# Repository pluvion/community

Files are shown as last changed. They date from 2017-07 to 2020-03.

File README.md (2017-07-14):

# Pluvi.On – Hackeando a chuva (Hacking the rain)
Image of Pluvion
 
Hoje no Brasil, existem aproximadamente 30 milhões de brasileiros expostos ao risco de enchentes e inundações. Além disso, existe uma projeção de impacto financeiro, onde as potenciais perdas anuais podem chegar a 4 bilhões de dólares até 2030 (Fonte: Swiss Re)

_Today in Brazil, there are approximately 30 million Brazilians exposed to the risk of flash floods and river floods. Moreover, there is financial impact: potential annual losses can reach 4 billion dollars by 2030 (Source: Swiss Re)_

Olhando este cenário alarmante iniciamos o desenvolvimento do Pluvi.On em jun/2016. Hoje somos um serviço de medição de chuva em tempo real e hiperlocalmente que envia informações de volume e intensidade da precipitação para quem precisar, população, entes governamentais e empresas.

_Looking at this alarming scenario we started the development of Pluvi.On in jun / 2016. Today we are a real-time and hyperlocal rainfall service that sends accumulated volume and precipitation rate data to anyone who needs it, population, government entities and companies._

Nosso sonho grande consiste em desenvolver novas estratégias de alerta de riscos (inundações, deslizamentos e chuvas intensas) para toda a população. Se possível, de maneira barata e escalável para que esta informação chegue a quem realmente precisa.

_Our big dream is to develop new risk alert strategies (floods, landslides and heavy rains) for the entire population. If possible, cheaply and scalable enough that this information gets to who really needs it._

Uma parte importante de tudo isso é o Pluvi.On, uma estação meteorológica Open Source e de baixo custo para ser espalhada na maior quantidade de pontos da cidade que pudermos!!! Chega de blá blá blá e vamos ao que interessa:

_An important part of all this is Pluvi.On itself, an inexpensive Open Source weather station to be spread out in as many points of the city as we can !!! That&#39;s enough talk let&#39;s see what matters:_

Você pode checar neste link todas as instruções para construção do seu próprio Pluvi!

_You can check in this link all the instructions for building your own Pluvi!_

https://www.instructables.com/member/PluviOn/

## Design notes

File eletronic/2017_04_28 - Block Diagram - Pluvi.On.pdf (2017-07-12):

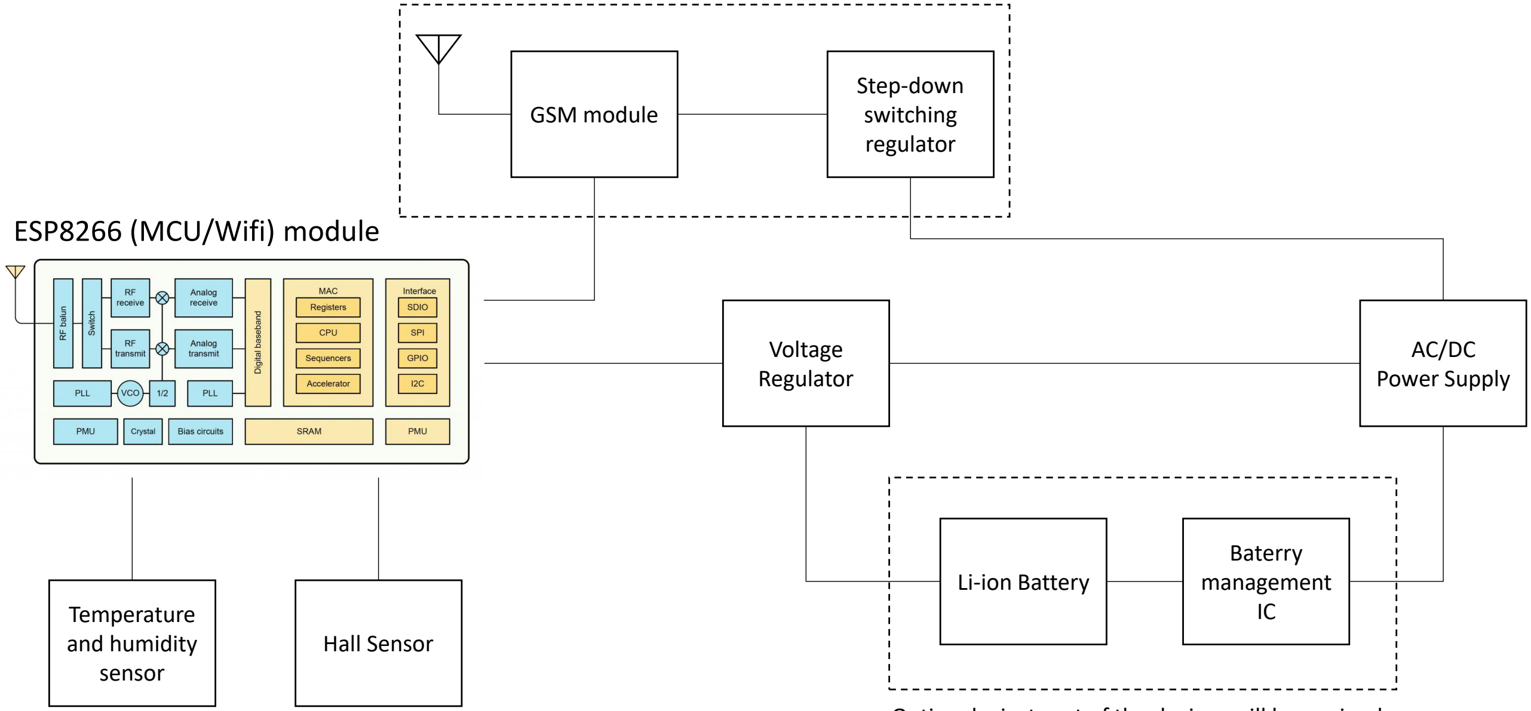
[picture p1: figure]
ESP8266 (MCU/Wifi) module; Hall Sensor; Temperature and humidity sensor; AC/DC Power Supply; Voltage Regulator; Li-ion Battery; GSM module; Baterry management IC; Step-down switching regulator

Optional – just part of the devices will be equiped with redundant power source

Optional – installed only when wifi is not available

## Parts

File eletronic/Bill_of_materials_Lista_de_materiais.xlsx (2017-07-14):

Descrição Portugues | English Description | Link | Qtd por unidade
Kit Colagem Acrilico / Cola S-320 / B25 | Acrylic Welding Kit S-320 / B25 |  | 20 ml
Sensor de Temperatura e Umidade DHT22 | Temperature and Humidity Sensor DHT22 | https://www.sparkfun.com/datasheets/Sensors/Temperature/DHT22.pdf | 1
Placa acrilico (480 mm x 300 mm x 2,4 mm) | Acrylic sheet (480 mm x 300 mm x 2.4 mm) | http://www.macedoplasticos.com.br/acrilicos.html | 1
Imã de neodimio N35 (4x2mm) | Neodymium magnet N35 (4x2mm) | http://www.imashop.com.br/ima-neodimio-n35-disco-4x2-mm-d0402p/p | 1
Sensor Hall (DRV5023 SMD) | Hall Sensor (DRV5023 SMD) | http://www.ti.com/product/DRV5023 | 1
Resistor 0805 10K SMD | Resistor 0805 10K SMD | http://www.mouser.com/ProductDetail/Kamaya/RMC1-10K1200FTP/ | 2
Capacitor Ceramico 0805 10uF SMD | Ceramic Capacitor 0805 10uF SMD | http://www.mouser.com/ProductDetail/Vishay-Vitramon/VJ0805G106KXQTW1BC/ | 1
Conector 1014 femea 14 pinos para barra de pinos | Flip pin 14 pins | https://www.sparkfun.com/products/14086 | 2
Barra de Pinos 90 graus | Break Away Male Headers - Right Angle | https://www.sparkfun.com/products/553 | 2 pinos
Barra de Pinos reto | Break Away Headers - Straigh | https://www.sparkfun.com/products/116 | 2 pinos
Conector femea c/ shell | 2-pin Wire to board connector 2.54 | https://www.alibaba.com/product-detail/17-pin-electronic-wire-to-board_60602562246.html | 2
Nodemcu LoLin v3 | Nodemcu LoLin v3 | https://github.com/nodemcu/nodemcu-devkit | 1
Fonte DC 5V 500mA ou maior | DC 5V 500mA Power Supply | https://www.sparkfun.com/products/12889 | 1
Tipping Bucket - Fabricado conforme projeto | Tipping Bucket - Manufactured according to design | https://github.com/pluvion/community/blob/master/design/3D_Parts/Bucket_onepiece.stl | 1
Stevenson Screen - Fabricado conforme projeto | Stevenson Screen - Manufactured according to design | https://github.com/pluvion/community/blob/master/design/3D_Parts/Stevenson_screen.stl | 1
PCB - Fabricado conforme projeto | PCB - Manufactured according to design | https://github.com/pluvion/community/tree/master/eletronic | 1
Passa Fio de borracha 3 mm | Grommet 3 mm | https://www.alibaba.com/product-detail/Custom-made-waterproof-molded-OEM-rubber_60619949840.html | 2
Eixo de latão usinado ou pino de 40 x 2,65 mm | Machined brass shaft or simple stainless pin 40 x 2.65 mm | https://www.alibaba.com/product-detail/High-quality-precision-M2-Stainless-steel_60147705078.html | 1
Fita Hellerman | Assorted Cable ties | https://www.hellermanntyton.com/products/cable-ties-inside-serrated/t80r/111-08010 | 2
Pincel | Brush |  | Tools
Ferro de solda / Estacao de solda | Soldering Iron / Soldering Station |  | Tools
Cola quente | Hot Glue |  | Tools

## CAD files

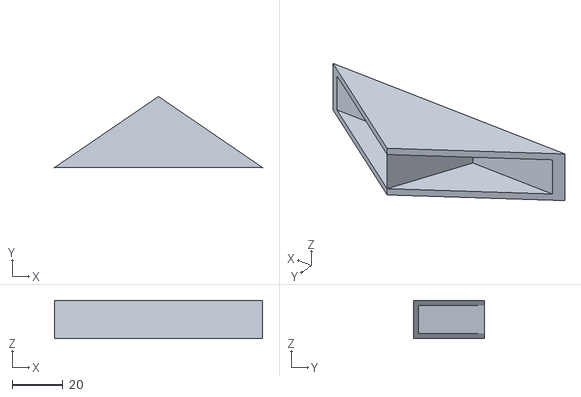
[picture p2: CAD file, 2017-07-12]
design/3D_Parts/Bucket_main.stl
82.0 x 28.0 x 15.0

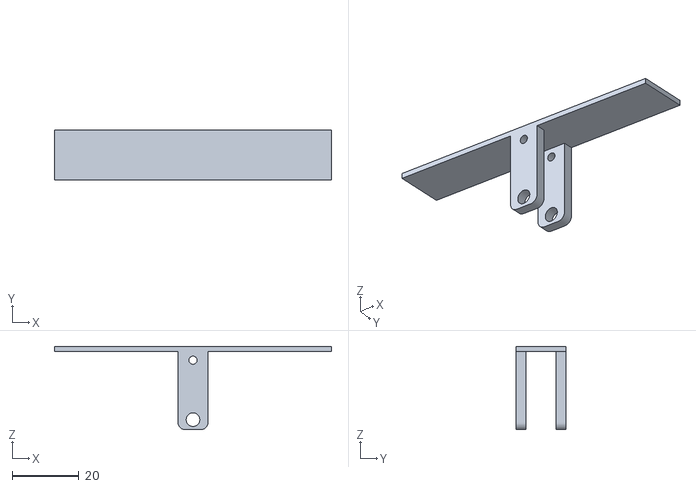
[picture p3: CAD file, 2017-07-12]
design/3D_Parts/Bucket_Base.stl
83.0 x 15.0 x 25.0

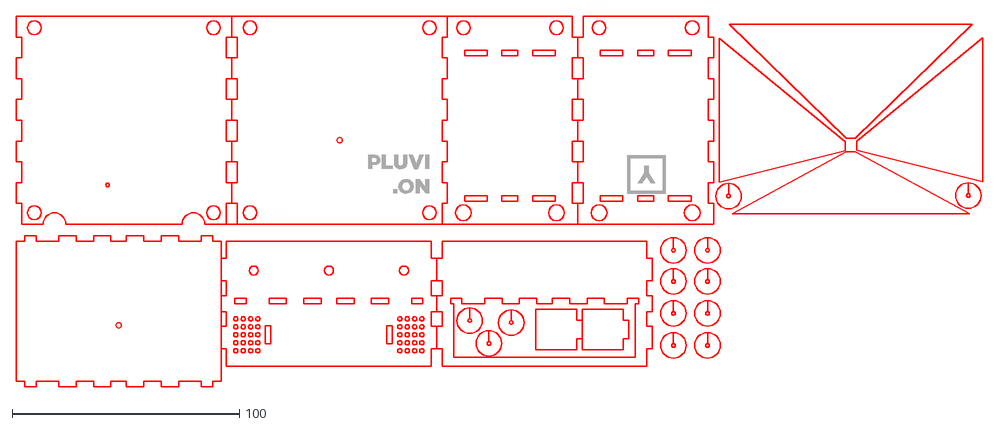
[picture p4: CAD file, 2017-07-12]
design/Lasercut_Parts/Pluvion_community_2D.dxf
425.8 x 163.1

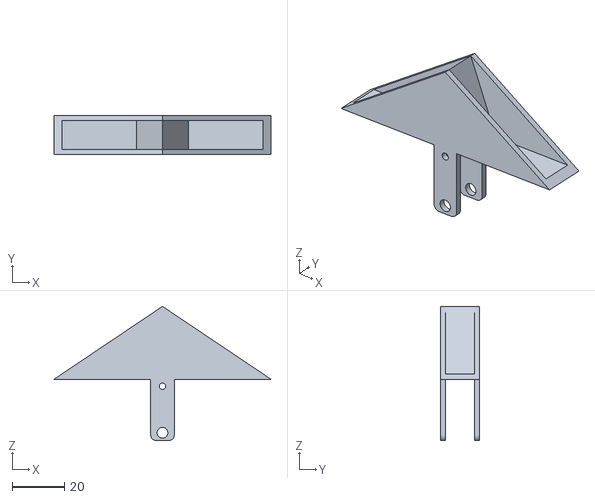
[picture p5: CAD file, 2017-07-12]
design/3D_Parts/Bucket_onepiece.stl
83.0 x 15.0 x 51.4

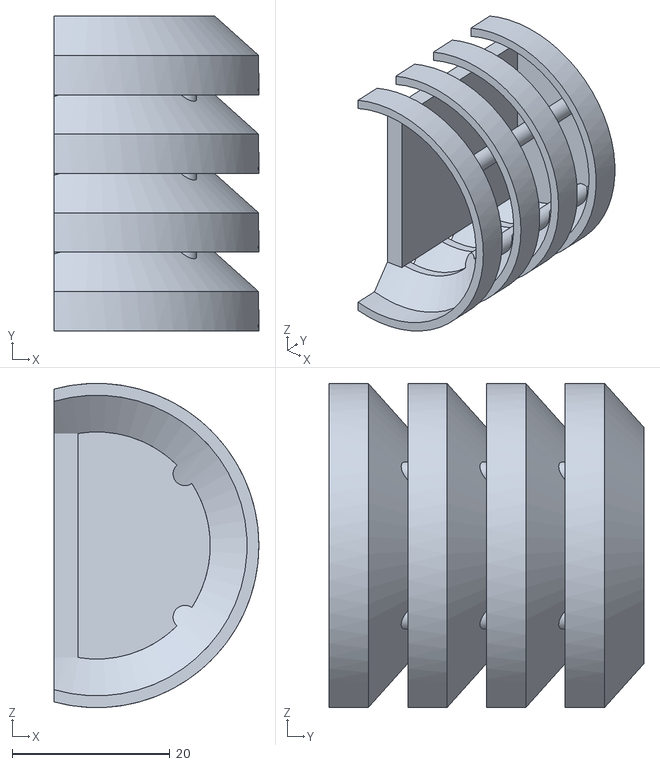
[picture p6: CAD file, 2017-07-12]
design/3D_Parts/Stevenson_screen.stl
26.0 x 40.0 x 41.2

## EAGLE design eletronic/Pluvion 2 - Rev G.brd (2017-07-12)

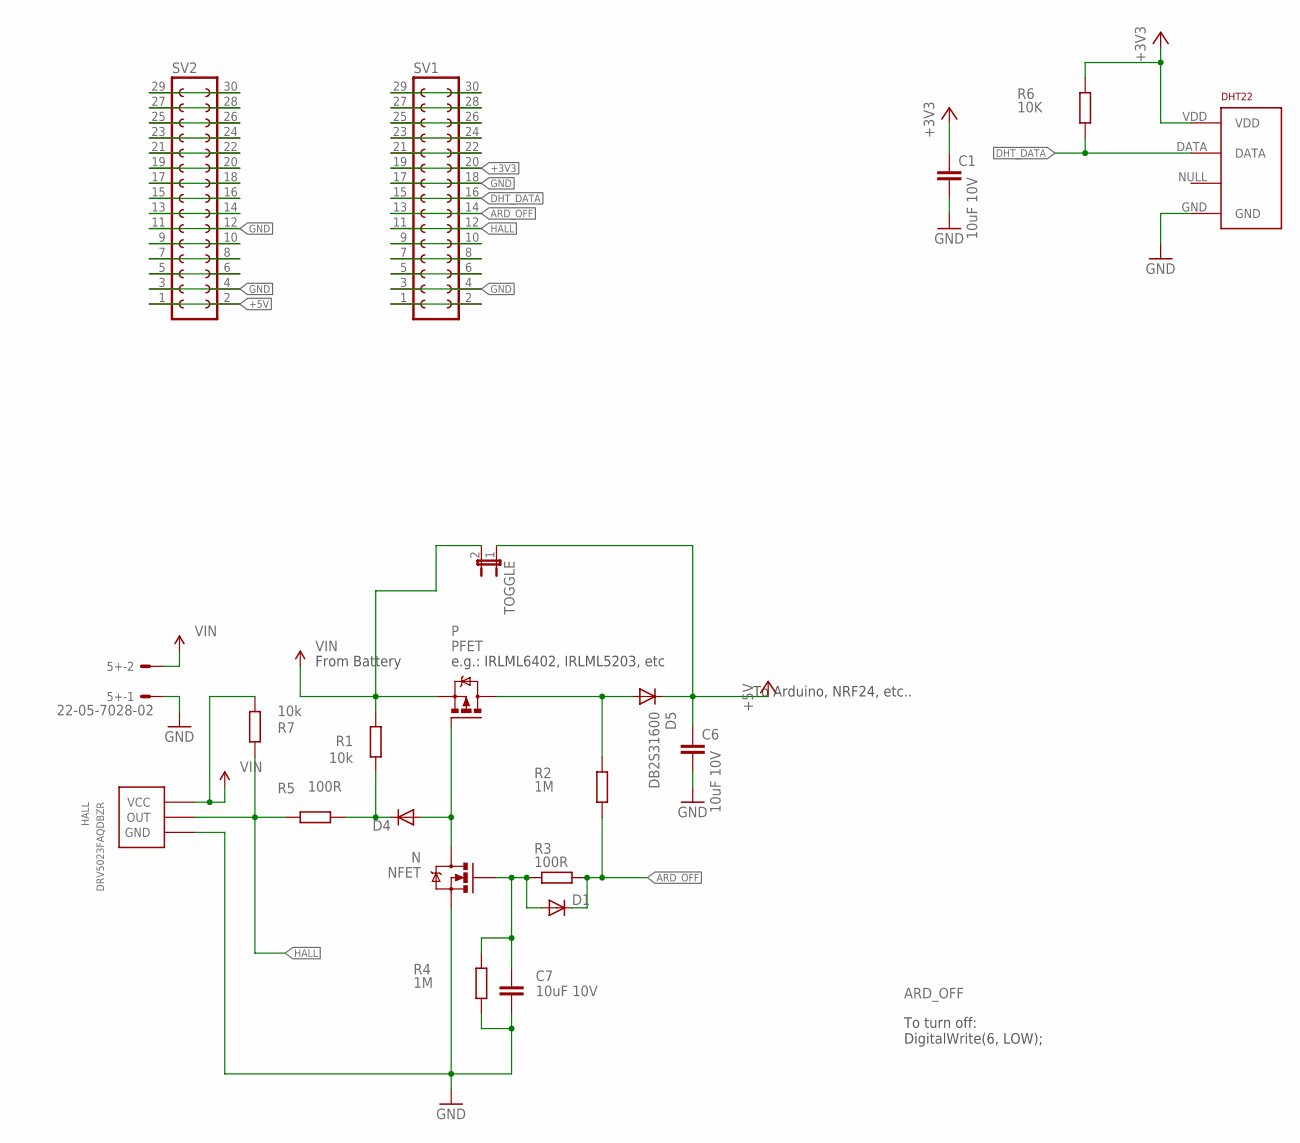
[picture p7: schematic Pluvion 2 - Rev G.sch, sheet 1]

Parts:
5+: 22-05-7028-02; 7395-02
C1, C6, C7: 10uF 10V; C0805
D1, D4: DIODESOD; SOD-323
D5: DB2S31600; SMA-DIODE
DHT22: RHT03_DHT-22_AM2302RA; RHT03_DHT-22/RA
HALL: DRV5023FAQDBZR; SOT23
N: NFET; SOT23
P: PFET; MICRO3
R1, R7: 10k; R0805
R2, R4: 1M; R0805
R3, R5: 100R; R0805
R6: 10K; R0805
SV1, SV2: FE15-2
TOGGLE: JUMPER-2PTH; 1X02

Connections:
+3V3: C1.1, DHT22.VDD, R6.2, SV1.19, SV1.20
+5V: C6.1, D5.C, SV2.1, SV2.2, TOGGLE.1
ARD_OFF: D1.1 (C), R2.1, R3.2, SV1.13, SV1.14
BUTTONS: D4.2 (A), N.3 (D), P.1 (G)
DHT_DATA: DHT22.DATA, R6.1, SV1.15, SV1.16
GND: 5+.1, C1.2, C6.2, C7.2, DHT22.GND, HALL.3 (GND), N.2 (S), R4.1, SV1.3, SV1.4, SV1.17, SV1.18, SV2.3, SV2.4, SV2.11, SV2.12
HALL: HALL.2 (OUT), R5.2, R7.2, SV1.11, SV1.12
unnamed: D5.A, P.3 (D), R2.2
unnamed: C7.1, D1.2 (A), N.1 (G), R3.1, R4.2
unnamed: SV1.1, SV1.2
unnamed: SV1.5, SV1.6
unnamed: SV1.7, SV1.8
unnamed: SV1.9, SV1.10
unnamed: D4.1 (C), R1.1, R5.1
unnamed: SV1.21, SV1.22
unnamed: SV1.23, SV1.24
unnamed: SV1.25, SV1.26
unnamed: SV1.27, SV1.28
unnamed: SV1.29, SV1.30
unnamed: SV2.5, SV2.6
unnamed: SV2.7, SV2.8
unnamed: SV2.9, SV2.10
unnamed: SV2.13, SV2.14
unnamed: SV2.15, SV2.16
unnamed: SV2.17, SV2.18
unnamed: SV2.19, SV2.20
unnamed: SV2.21, SV2.22
unnamed: SV2.23, SV2.24
unnamed: SV2.25, SV2.26
unnamed: SV2.27, SV2.28
unnamed: SV2.29, SV2.30
VIN: 5+.2, HALL.1 (VCC), P.2 (S), R1.2, R7.1, TOGGLE.2

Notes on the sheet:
e.g.: IRLML6402, IRLML5203, etc
To Arduino, NRF24, etc..
To turn off: DigitalWrite(6, LOW);
From Battery

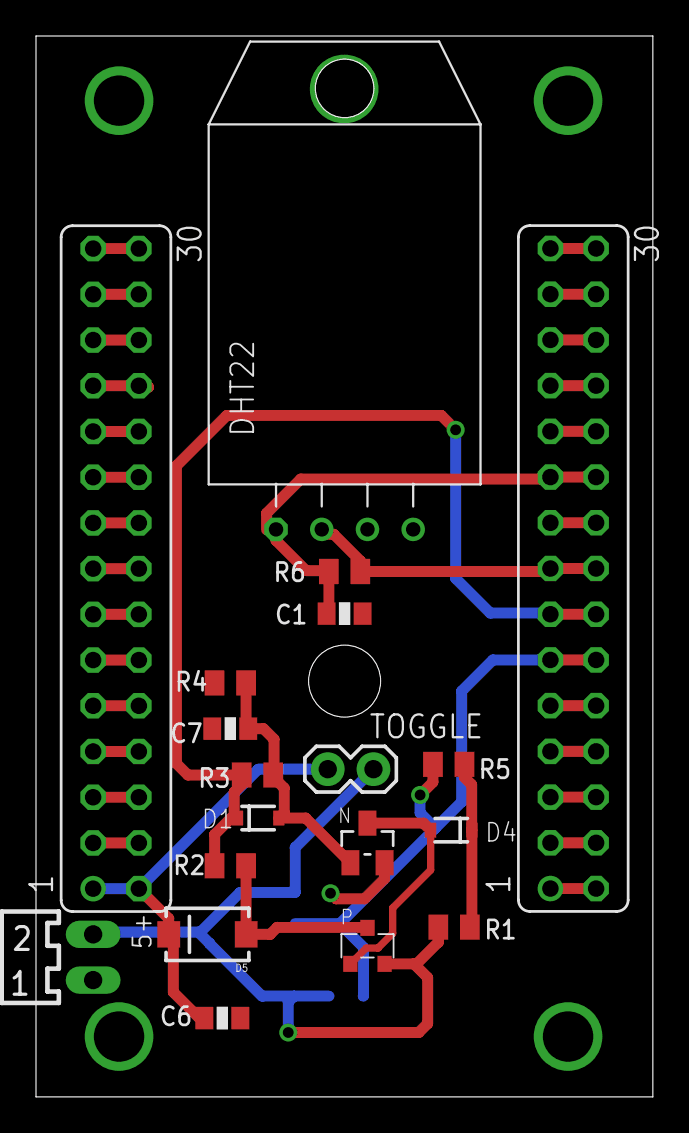
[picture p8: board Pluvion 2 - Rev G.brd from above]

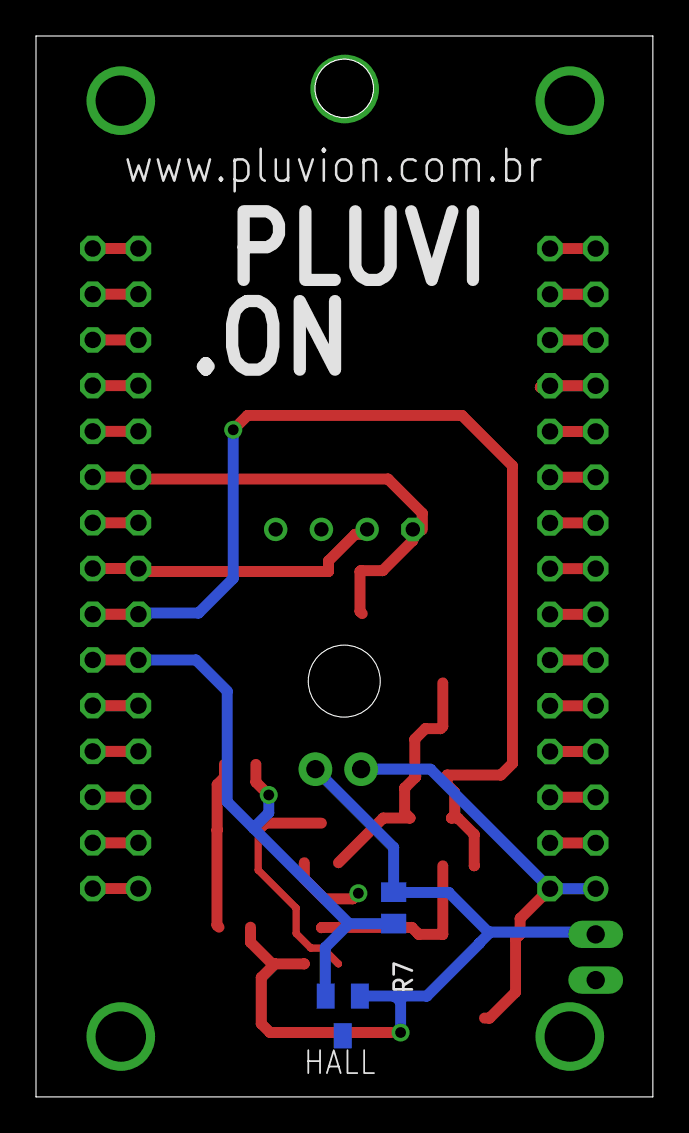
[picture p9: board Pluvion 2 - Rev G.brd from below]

Board: 2 copper layers, 34.3 x 58.9 mm, 21 parts (2 on the bottom side), 32 nets.

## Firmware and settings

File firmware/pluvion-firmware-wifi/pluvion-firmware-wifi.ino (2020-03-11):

/**
 * Pluvi.On WiFi Firmware
 * 
 *       FILE: pluvion_firwmware_wifi.ino
 *    VERSION: 2.0.0.W
 *    LICENSE: Creative Commons 4
 *    AUTHORS:
 *             Pedro Godoy <pedro@pluvion.com.br>
 *             Hugo Santos <hugo@pluvion.com.br>
 * 
 *       SITE: https://www.pluvion.com.br
 */
#include <FS.h>
#include <DHT.h>
#include <ESP8266WiFi.h>
#include <WiFiUdp.h>
#include <PluviOn.h>
PluviOn utils;

/////ATTENTION!!!! CHANGES SHOULD BE DONE IN COMPILATION TIME///
///BEGIN
// STATION CONFIG
const char *ssid           = "PG_hotspot";
const char *password       = "0102030405";
const String STATION_ID    = "31";
#define  SLEEP_PERIOD      900000 //15 minutes
#define SERVER_ADDR        "3.87.153.3"
#define SERVER_PORT      10000
///END
/////ATTENTION!!!! CHANGES SHOULD BE DONE IN COMPILATION TIME///

// WIFI
WiFiClient wf_client;

// SYSTEM SLEEP CONTROL
unsigned long sleepCounter = 0; // Sleep time counter


// SYSTEM DEFINES
#define SYSTEM_BAUDRATE 115200
const String DATA_DIR = "/data";
bool fs_is_active = false;

// PINS DEFINES
#define PIN_RESET_MONO D1 // pin reset mono
#define PIN_DHT D5        // pin where the dht22 is connected
#define PIN_SYSTEM_FORMAT D6 // pin full reset
#define PIN_HALL D7       // pin where Hall sensor is connected
#define PIN_RTC_SDA GPIO_ID_PIN(2)
#define PIN_RTC_SCL GPIO_ID_PIN(4)

// TEMPERATURE + HUMIDITY SENSOR
#define DHT_TYPE DHT22 //DHT type
DHT dht(PIN_DHT, DHT_TYPE, 20); // Initialize DHT sensor
#define DHT_SENSOR_READING_DELAY 600000
#define DHT_SENSOR_READING_FAILURE_DELAY 180000
#define DHT_SENSOR_READING_FAILURE_ATTEMPTS_LIMIT 2
unsigned long lastDHTReadingInMillis = 0;    // The last DHT reading time in ms
unsigned long currentDHTReadingInMillis = 0; // Current DHT reading in millis
boolean DHTSensorReadingFailure = false;
int DHTSensorFailedReadingAttempts = 0;
volatile float humidity = 0;          // Read air humidity in %
volatile float temperature = 0;       // Read temperature as Celsius
volatile float computedHeatIndex = 0; // Compute heat index in Celsius

// RAIN SENSOR
#define DELAY_HALL_SENSOR_DEBOUNCING 100 // Delay in ms to debounce hall sensor
volatile int tipCounter = 0;             // Store the bucket tip counter
volatile int realTipCount = 0;           // Checked tip counter
volatile int lastTipCount = 0;           // The last tip count total
unsigned long curBucketReadingInMs = 0;  // Current rain sensor reading in millis
unsigned long lastBucketReadingInMs = 0; // The last rain sensor reading time in ms
const float CONTRIBUTION_AREA = 7797.0; // Contribuition area in mm2
volatile float rainVolume = 0;          // The rain accumulated volume

void init_dht() {
  dht.begin();
}

void count_tip_bucket() {
  tipCounter++;
  Serial.print(F("[count_tip_bucket] - Tip counter: "));
  Serial.println(tipCounter);
  Serial.print(F("[count_tip_bucket] - Real tip count: "));
  Serial.println(realTipCount);
  Serial.print(F("[count_tip_bucket] - Last tip count: "));
  Serial.println(lastTipCount);
  detachInterrupt(PIN_HALL);
  read_hall_sensor();
  attach_interruption();
  }

void attach_interruption() {
  Serial.println(F("[attach_interruption] - Attaching"));
  attachInterrupt(PIN_HALL, count_tip_bucket, FALLING);
  Serial.println(F("[attach_interruption] - Done"));
}

void read_hall_sensor() {
  // Current millis mark
  curBucketReadingInMs = millis();

  // Check if the configured delay has passed
  if (
      ((curBucketReadingInMs - lastBucketReadingInMs) > DELAY_HALL_SENSOR_DEBOUNCING) || // delay
      (lastBucketReadingInMs == 0)                                                       // first time
  ) {
    // Any increment since the last time?
    if (tipCounter > lastTipCount) {

      // Increase the tip bucket count
      realTipCount++;
      Serial.print(F("REAL TIP COUNT: "));
      Serial.println(realTipCount);

      // Update last tip counter value
      lastTipCount = tipCounter;
    }

    // Store the current millis for the next iteration
    lastBucketReadingInMs = curBucketReadingInMs;
  }
}

void read_dht_sensor() {
  // Current millis mark
  currentDHTReadingInMillis = millis();

  if (
    DHTSensorReadingFailure &&                                                                    // Fail
    ((currentDHTReadingInMillis - lastDHTReadingInMillis) >= DHT_SENSOR_READING_FAILURE_DELAY) && // The time hasn' passed yet
    (DHTSensorFailedReadingAttempts <= DHT_SENSOR_READING_FAILURE_ATTEMPTS_LIMIT)                 // Number of attempts
  ) {
    Serial.println(F("[read_dht_sensor] - DHT reading failure"));
    Serial.print(F("[read_dht_sensor] - DHT reading retries: "));
    Serial.println(DHTSensorFailedReadingAttempts);

    DHTSensorFailedReadingAttempts++;

    Serial.println(F("[read_dht_sensor] - Reading DHT..."));
    get_dht_data();
  }

  // Check if the configured delay has passed
  if ((currentDHTReadingInMillis - lastDHTReadingInMillis) >= DHT_SENSOR_READING_DELAY || // delay
    (lastDHTReadingInMillis == 0)                                                         // first time
  ) {
    Serial.println(F("[read_dht_sensor] - Reading DHT..."));
    get_dht_data();
  }
}

void get_dht_data() {

  // Reading temperature or humidity takes about 250 milliseconds!
  // Sensor readings may also be up to 2 seconds 'old' (its a very slow sensor)
  humidity = dht.readHumidity();

  // Read temperature as Celsius
  temperature = dht.readTemperature();

  // Check if any reads failed and exit early (to try again).
  if (isnan(humidity) || isnan(temperature)) {
    Serial.println(F("[get_dht_data] - ERROR - Failed to read from DHT sensor!"));

    // Indicates a failure in readings
    DHTSensorReadingFailure = true;

    // Fix humidity, temperature and computed heat index
    humidity = isnan(humidity) ? -999 : humidity;
    temperature = isnan(temperature) ? -999 : temperature;
    computedHeatIndex = -999;

    // Store the current millis for the next iteration
    lastDHTReadingInMillis = currentDHTReadingInMillis;

    return;
  }

  // Reset failure flags
  DHTSensorFailedReadingAttempts = 0;
  DHTSensorReadingFailure = false;

  // Compute heat index in Celsius (isFahreheit = false)
  computedHeatIndex = dht.computeHeatIndex(temperature, humidity, false);
  computedHeatIndex = (computedHeatIndex > 100) ? 0 : computedHeatIndex;

  Serial.print(F("[get_dht_data] - temperature (C)      : "));
  Serial.println(temperature);

  Serial.print(F("[get_dht_data] - humidity (%)         : "));
  Serial.println(humidity);

  Serial.print(F("[get_dht_data] - computedHeatIndex (C): "));
  Serial.println(computedHeatIndex);

  // Store the current millis for the next iteration
  lastDHTReadingInMillis = currentDHTReadingInMillis;
}

void print_fs_info() {
  FSInfo fs_info;
  SPIFFS.info(fs_info);

  float used_space = (float) fs_info.usedBytes/fs_info.totalBytes;
  float free_space = (float) (1 - used_space);

  Serial.print(F("[print_fs_info] - Filesystem Total: "));
  Serial.println(fs_info.totalBytes);

  Serial.print(F("[print_fs_info] - Filesystem Used: "));
  Serial.println(fs_info.usedBytes);

  Serial.print(F("[print_fs_info] - Filesystem Used %: "));
  Serial.println(used_space);

  Serial.print(F("[print_fs_info] - Filesystem Free %: "));
  Serial.println(free_space);
}

void read_sensors() {
  Serial.println(F("[read_sensors] - Begin"));

  // Reads the hall sensor
  read_hall_sensor();

  // Reads the DHT Sensor Info
  read_dht_sensor();

  Serial.println(F("[read_sensors] - Done"));
}

void save_message(String message){
  Serial.print(F("[save_message] - Saving Message: \""));
  Serial.print(message);
  Serial.println(F("\""));

  Serial.print(F("[save_message] - Free Space: "));
}
  
int wifi_quality() {
  long rssi = WiFi.RSSI();

  int percent = 0;
  if(rssi > -50) {
    percent = 100;
  } else if(rssi > -55) {
    percent = 90;
  } else if(rssi > -62) {
    percent = 80;
  } else if(rssi > -65) {
    percent = 70;
  } else if(rssi > -68) {
    percent = 60;
  } else if(rssi > -74) {
    percent = 50;
  } else if(rssi > -79) {
    percent = 40;
  } else if(rssi > -83) {
    percent = 30;
  } else if(rssi > -88) {
    percent = 20;
  } else if(rssi > -93) {
    percent = 10;
  }

  Serial.print("[wifi_quality] - rssi/percent: ");
  Serial.print(rssi);
  Serial.print(F("/"));
  Serial.println(percent);

  return percent;
}

float fs_free_space() {
  FSInfo fs_info;
  SPIFFS.info(fs_info);

  float used_space = (float) fs_info.usedBytes/fs_info.totalBytes;
  float free_space = (float) (1 - used_space);

  Serial.print("[fs_free_space] - Used: ");
  Serial.println(used_space);

  Serial.print("[fs_free_space] - Free: ");
  Serial.println(free_space);

  return free_space;
}

String build_message() {
  String message = "i;";

  message += STATION_ID;
  message += ";";

  message += realTipCount;
  message += ";";

  message += "0;"; // Raining

  message += temperature;
  message += ";";

  message += humidity;
  message += ";";

  message += wifi_quality();
  message += ";";

  message += "0"; // crc

  Serial.print(F("[build_message] - Message (i;id;timestamp;bt;raining;tp;rh;sigs;crc): "));
  Serial.println(message);

  return message;
}

void delete_messages(String send_result){

  if(send_result == "ok") {
    Serial.println(F("[delete_messages] - Deleting files:"));
    utils.FSPrintFileList();
  
    utils.FSDeleteFiles(DATA_DIR);
    Serial.println(F("[delete_messages] - Done."));
  
    Serial.println(F("[delete_messages] - File list:"));
    utils.FSPrintFileList();
  } else {
    Serial.print(F("[delete_messages] - Can't delete, socket response: '"));
    Serial.print(send_result);
    Serial.println(F("'"));
  }
}

String read_messages() {
  Serial.println(F("[read_messages]"));
}

String send_messages() {
  if(fs_is_active){
    // Open directory
    Dir dir = SPIFFS.openDir(DATA_DIR);
    Serial.print(F("[send_messages] - Files in \""));
    Serial.print(DATA_DIR);
    Serial.println(F("\" directory:"));
    Serial.println(F("[send_messages] - ---------"));
    File f;
    String messages;
    while (dir.next()) {
      Serial.print(F("[send_messages] - "));
      Serial.println(dir.fileName());
      // Open file
      f = SPIFFS.open(dir.fileName(), "r");

      if (!f) {
        Serial.print(F("[send_messages] - Unable To Open '"));
        Serial.print(dir.fileName());
        Serial.println(F("' for Reading"));
      } else {

        // Group messages
        while (f.position() < f.size()) {
          messages += f.readStringUntil('\n');
          messages += '\n';
        }

        f.close();
      }
    }

    Serial.println(F("[send_messages] - Message payload:"));
    Serial.print(messages);
    
    // Send all messages
    return send_message(messages);

  } else {
      Serial.println(F("[send_messages] - Filesystem is not mounted"));
      return "not_mounted";
  }
}

String send_message(String message){
  String result = "";

  Serial.print(F("[send_message] - Connecting to "));
  Serial.print(SERVER_ADDR);
  Serial.print(":");
  Serial.println(SERVER_PORT);

  boolean wf_connected = wifi_connected();

  if(wf_connected > 0) {
    Serial.println(F("[send_message] - Connected!"));
    Serial.println(F("[send_message] - Transmitting message: "));
    Serial.print(message);
  
    // Post Data
    wf_client.print(message);

    Serial.println(F("[send_message] - Handling response"));

    // Handle result
    while (wf_client.connected()) {
      if (wf_client.available()) {
        result = wf_client.readStringUntil('\r');
        Serial.print(F("[send_message] - Return: "));
        Serial.println(result);
        break;
      }
    }

    Serial.println(F("[send_message] - Closing connection"));

    // Close connection
    wf_client.stop();
    
  } else {
    Serial.println(F("[send_message] - FAIL - Can't connect, can't transmit, aborted."));
  }

  Serial.println(F("[send_message] - Done"));
  return result;
}

void init_fs(){
  Serial.println(F("[init_fs] - Begin"));

  if (SPIFFS.begin()) {
    fs_is_active = true;
    Serial.println(F("[init_fs] - SPIFFS is active"));
  } else {
    Serial.println(F("[init_fs] - FATAL! Unable to activate SPIFFS"));
    while(1);
  }

  Serial.println(F("[init_fs] - Done"));
}

void wifi_init() {
  wifi_setup();
  wifi_connected();
}

void wifi_setup() {
  Serial.print(F("[wifi_setup] - Connecting to SSID: "));
  Serial.println(ssid);
  WiFi.begin(ssid, password);
  while (WiFi.status() != WL_CONNECTED) {
    delay(500);
    Serial.print(".");
  }
}

boolean wifi_connected() {
  Serial.print(F("[wifi_connected] - Connecting to SSID: "));
  Serial.println(ssid);

  int conn_counter = 20;
  while (!wf_client.connect(SERVER_ADDR, SERVER_PORT)) {
    Serial.print(F("[wifi_connected] - Connection Failed ("));
    Serial.print(conn_counter);
    Serial.println(F(")"));

    delay(1000);
    
    conn_counter--;

    if(conn_counter < 0) break;
  }
  
  if(conn_counter > 0) {
    Serial.println(F("[wifi_connected] - WiFi Connected"));
    return true;
  } else {
    Serial.println(F("[wifi_connected] - WiFi NOT Connected"));
    return false;
  }
}

 
/**
 * Put the system to sleep
 */
void system_sleep() {
//  wifi_set_sleep_type(LIGHT_SLEEP_T);
  Serial.println(F("[system_sleep] - Modem is sleeping"));

  delay(SLEEP_PERIOD);
//  unsigned long sleepCounter = millis();
//  while ((millis() - sleepCounter) < SLEEP_PERIOD);

  Serial.println(F("[system_sleep] - Modem up and running"));
}

void init_ntp() {
  Serial.println(F("[init_ntp] - Starting"));
  
  Serial.println(F("[init_ntp] - Updating"));
  
  Serial.println(F("[init_ntp] - Done"));
}

void format_fs() {
  Serial.println(F("[format_fs] - Formatting File System, please wait..."));
  utils.FSFormat();
  Serial.println(F("[format_fs] - Done."));
}

void config_pins() {
  Serial.println(F("[config_pins] - Begin"));

  // RAIN
  pinMode(PIN_HALL, INPUT_PULLUP);

  // RESET
  pinMode(PIN_RESET_MONO, OUTPUT);
  digitalWrite(PIN_RESET_MONO, HIGH);
  pinMode(PIN_SYSTEM_FORMAT, INPUT_PULLUP);
  if (digitalRead(PIN_SYSTEM_FORMAT) == 0) {
    Serial.println(F("[config_pins] - Format FS pin active. Formatting..."));
    format_fs();
  }

  Serial.println(F("[config_pins] - Done"));
}

void reset_bucket_tip_counter() {
  Serial.print(F("[reset_bucket_tip_counter] - Tip counter: "));
  Serial.println(tipCounter);

  Serial.print(F("[reset_bucket_tip_counter] - Real tip count: "));
  Serial.println(realTipCount);

  Serial.print(F("[reset_bucket_tip_counter] - Last tip count: "));
  Serial.println(lastTipCount);

  lastTipCount = 0;
  realTipCount = 0;
  tipCounter = 0;
  rainVolume = 0;
}

void setup() {
  Serial.begin(SYSTEM_BAUDRATE);

  Serial.println(F("\n\n[setup] - Init =========================="));
  
  config_pins();

  wifi_init();

  init_fs();

//  format_fs();

  init_dht();
    
  attach_interruption();
}

void loop() {
  Serial.println(F("\n\n[loop] - Begin =========================="));
  read_sensors();
  String message = build_message();
  reset_bucket_tip_counter();
//  save_message(message);
  String send_result = send_messages();
//  delete_messages(send_result);
  attach_interruption();
  system_sleep();
}

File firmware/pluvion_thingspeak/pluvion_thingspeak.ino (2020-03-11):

/**
 * Pluvi.On WiFi Community Firmware
 * 
 *       FILE: pluvion_community_firwmware.ino
 *    VERSION: 0.0.3.C
 *    LICENSE: Creative Commons 4
 *    AUTHORS:
 *             Pedro Godoy <pedro@pluvion.com.br>
 *             Hugo Santos <hugo@pluvion.com.br>
 * 
 *       SITE: https://github.com/pluvion/firmware
 *             https://www.pluvion.com.br
 */

// Insert your key here
const String apiKey = "VJXMP2062EHMRFT6"; // THINGSPEAK CHANNEL API KEY https://www.mathworks.com/help/thingspeak/channel-control.html

/********************
 * 
 * YOU DON'T NEED TO CHANGE ANYTHING BELOW THIS POINT
 * 
 *********************/

// Libraries
#include <FS.h> // FS must be the first
#include <DHT.h>
#include <ESP8266WiFi.h>
#include <WiFiManager.h>

// System Config (must come before #include <PluviOn.h>)
#define PLV_DEBUG_ENABLED true
#define PLV_SYSTEM_BAUDRATE 115200

#include <PluviOn.h>
PluviOn pluvion;

// Debug voltage in (enable ESP.getVcc())
ADC_MODE(ADC_VCC);

// PINS
#define PIN_DHT D5       // pin where the dht22 is connected
#define PIN_POWER_OFF D6 // pin where toggle is connected
#define PIN_HALL D7      // pin where Hall sensor is connected
#define PIN_ERASE D0

// |------------------------------------------|
// |     DHT Sensor Reading Interval in ms    |
// |------------------------------------------|
// |   INTERVAL  |   FREQ.  |  # MSGS/DAY     |
// |-------------|----------|-----------------|
// |  1.800.000  |  30 min  |     48 msg/day  |
// |  1.200.000  |  20 min  |     72 msg/day  |
// |    900.000  |  15 min  |     96 msg/day  |
// |    600.000  |  10 min  |    144 msg/day  |
// |    300.000  |   5 min  |    288 msg/day  |
// |     60.000  |   1 min  |  1.440 msg/day  |
// |     30.000  |  30 sec  |  2.880 msg/day  |
// |-------------|----------|-----------------|
//
// ATTENTION!
// You must consider the available storage size and the message size
// More messages, less space in case of lost connection

#define DHT_SENSOR_READING_DELAY 600000
#define DHT_SENSOR_READING_FAILURE_DELAY 180000
#define SEND_OFFLINE_MESSAGES_DELAY 120000

// READING PERIODS AND DEBOUNCE TIMERS
#define DELAY_HALL_SENSOR_DEBOUNCING 1000 // Delay in ms to debounce hall sensor

/**
 * Station Information
 */

// Configured at setup
float PLV_STATION_BUCKET_VOLUME = 3.22; // Bucket Calibrated Volume in ml
String STATION_LONGITUDE = "";
String STATION_LATITUDE = "";
String STATION_NAME = "PluviOn";
String STATION_ID = "";

const String STATION_ID_PREFIX = "PluviOn_";
const String FIRMWARE_VERSION = "0.0.3.C";

/**
 * File system directories and variables
 */
const String DIR_SYSTEM_DATA = "/sys";
const String DIR_WEATHER_DATA = "/weather";
const String DIR_MESSAGE_COUNTER = "/msgcnt";
const String DIR_FIRMWARE_VERSION = "/fmwver";
const String DIR_STATION_ID = "/stt/id";
const String DIR_STATION_NAME = "/stt/name";
const String DIR_STATION_BUCKET_VOL = "/stt/bucketvol";
const String DIR_STATION_TIME_TO_RESET = "/stt/ttr";
const String DIR_STATION_TIME = "/stt/time";
const String DIR_STATION_LATITUDE = "/stt/lat";
const String DIR_STATION_LONGITUDE = "/stt/lon";
const String FIELD_SEPARATOR = "|";

// Station time and reset timer
const int DEFAULT_RESET_PERIOD = 86400; // Default reset period 24 hours in seconds = 86400
unsigned long resetCicleCounter = 0;
int resetStartTime = 0;
int TIME_TO_RESET = 0;     // Time left until the next reset
int STATION_TIME = 0;      // Station time
boolean resetFlag = false; //

// Tipping Bucket Configurations
const float CONTRIBUTION_AREA = 7797.0; // Contribuition area in mm2
volatile int tipCounter = 0;            // Store the bucket tip counter
volatile float rainVolume = 0;          // The rain accumulated volume

// State Control Variables
unsigned long lastTipBucketReadingInMillis = 0;    // The last tip bucket (hall sensor) reading time in ms
unsigned long currentTipBucketReadingInMillis = 0; // Current tip bucket reading in millis
volatile float lastTipCount = 0;                   // The last tip count total
volatile int realTipCount = 0;                     // Checked tip counter

// DHT22 Sensor Variables and initialization
#define DHT_TYPE DHT22                // DHT 22  (AM2302)
volatile float humidity = 0;          // Read air humidity in %
volatile float temperature = 0;       // Read temperature as Celsius
volatile float computedHeatIndex = 0; // Compute heat index in Celsius

// State Control Variables
unsigned long lastDHTReadingInMillis = 0;    // The last DHT reading time in ms
unsigned long currentDHTReadingInMillis = 0; // Current DHT reading in millis

// Initialize DHT sensor
DHT dht(PIN_DHT, DHT_TYPE, 20);

// In case of DHT Sensor reading failure
#define DHT_SENSOR_READING_FAILURE_ATTEMPTS_LIMIT 2
boolean DHTSensorReadingFailure = false;
int DHTSensorFailedReadingAttempts = 0;

/**
 * Local Storage
 */
int messageID = 0;

/**
 * System Information
 */
float SYSAvailableDiskSpaceInPercent = 0.0;
int SYSAvailableDiskSpaceInBytes = 0;
int SYSAvailableHeapInBytes = 0;
String SYSLastResetReason = "";
String SYSWiFiHostname = "";
String SYSWiFiLocalIp = "";
String SYSWiFiMACAddr = "";
int SYSWiFiRSSIindBm = 0;
String SYSWiFiSSID = "";
int SYSVCCInV = 0;

// Initialize WiFiClient
WiFiClientSecure WIFISecureClient;
WiFiClient client;

// Initialize WiFiManager
WiFiManager wifiManager;

// Time to try
#define WIFI_CONN_COUNTER 1
// Delay to connect to WiFi (WIFI_CONN_DELAY X WIFI_CONN_COUNTER = time to access point mode)
#define WIFI_CONN_DELAY 30000

/**
 * Pluvi.On API
 */
const char *PLUVION_API_SERVER_ADDR = "api.community.pluvion.com.br";
const char *PLUVION_API_RESOURCE_WEATHER = "/weather";
const int PLUVION_API_SERVER_PORT = 443;
const int PLUVION_API_SERVER_REQ_TIMEOUT = 5000; // Request Timeout (ms)

// Pluvi.On Media Types Standard
//const String HTTP_HEADER_PLUVION_KEY = "X-PluviOn-Key: " + PLUVION_KEY;
const char *HTTP_HEADER_ACCEPT = "Accept: application/vnd.community.pluvion.com.br.v1.text";
const char *HTTP_HEADER_CONTENT_TYPE = "Content-Type: application/vnd.community.pluvion.com.br.v1.text";
const char *HTTP_HEADER_EOL = "\r\n";
const char *HTTP_HEADER_USER_AGENT = "User-Agent: Pluvi.On Community Station/1.0";

// Send offline messages
unsigned long currentBatchReadingInMillis = 0;
unsigned long lastBatchReadingInMillis = 0;
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

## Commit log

2017-07-14 updates BOM
    [Bill_of_materials_Lista_de_materiais.xlsx]
2017-09-11 OSX Sierra Driver

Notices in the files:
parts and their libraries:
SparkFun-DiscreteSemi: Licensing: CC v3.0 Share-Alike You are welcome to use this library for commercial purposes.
